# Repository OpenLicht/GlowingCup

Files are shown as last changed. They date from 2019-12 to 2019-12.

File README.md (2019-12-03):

# Glowing Cup

## Summary
The board measures the temperature and adjusts the color accordingly.
The Temperature is determined by three sensors, which provides the mean value
to the microcontroller. It processes and visualizes the data as a color via the built-in RGB LEDs. The board is charged wirelessly using Qi(pronounced CHEE) technology.

## Pictures
| | |
| --- | --- |
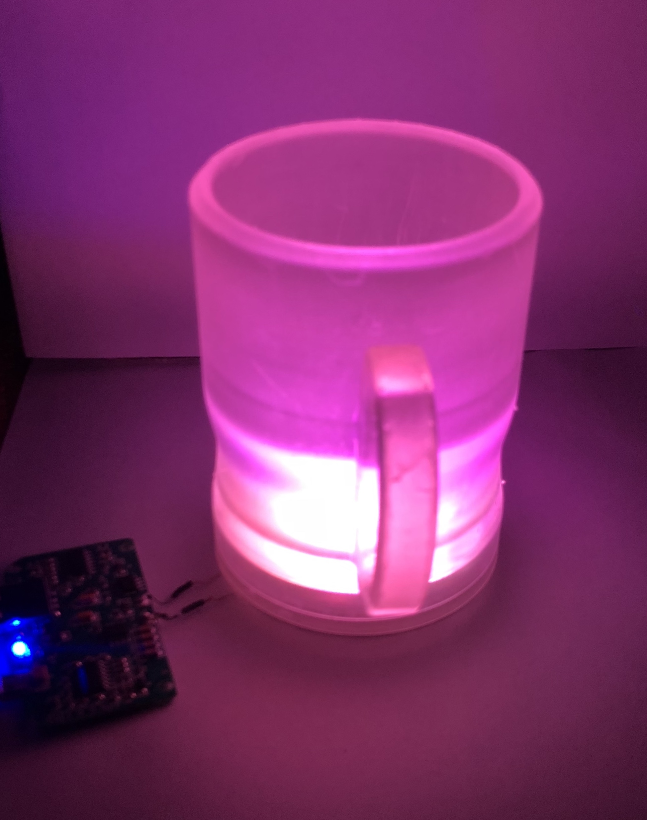
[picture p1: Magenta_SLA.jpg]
Bild1
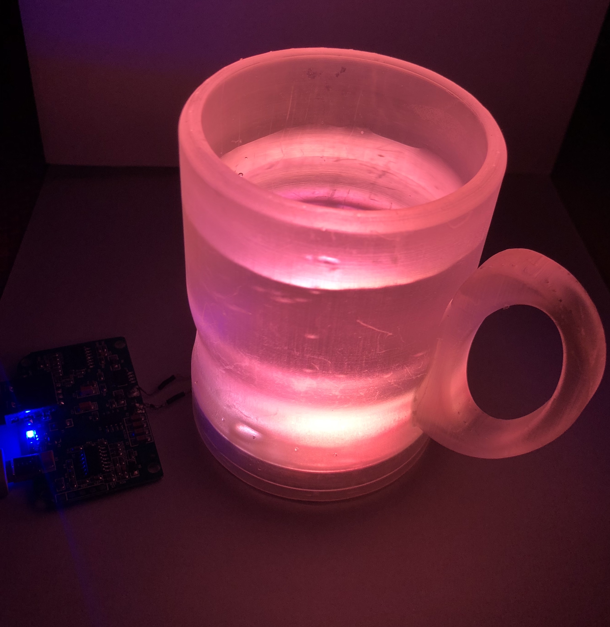
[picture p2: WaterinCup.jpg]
Bild2
|  |  |
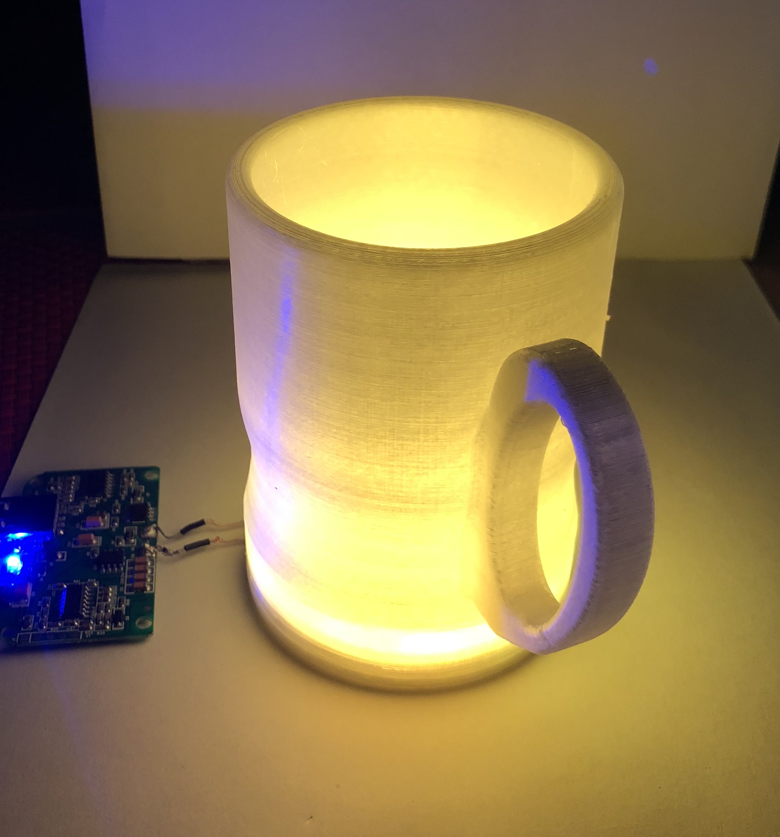
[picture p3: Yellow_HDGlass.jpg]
Bild3
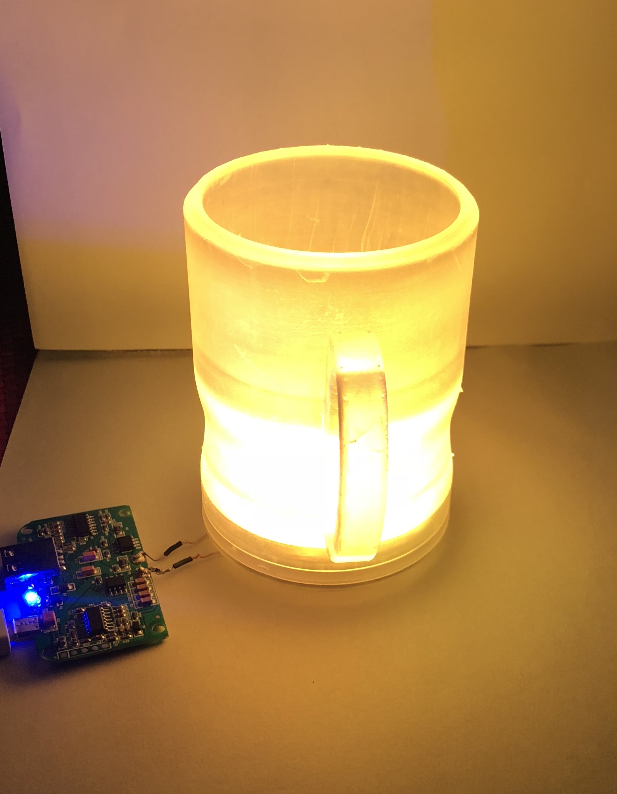
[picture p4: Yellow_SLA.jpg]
Bild4
|  |  |

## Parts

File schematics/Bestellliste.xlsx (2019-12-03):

Bauteile | Im Labor verfügbar? | Anzahl | Preis pro Stück | Kosten | Quelle |  | Nein
WR08X4701FTL - Chipwiderstand, Oberflächenmontage, 4.7 kohm, WR08 Series, 150 V, Dickschicht, 0805 [Metrisch 2012] | Nein | 4 | 0.044 | 0.1760 | http://de.farnell.com/walsin/wr08x4701ftl/dickschichtwiderstand-4k7-1-150v/dp/2502731?st=0805%20widerstand |  | Ja
WR08X1001FTL - Chipwiderstand, Oberflächenmontage, 1 kohm, WR08 Series, 150 V, Dickschicht, 0805 [Metrisch 2012] | Nein | 1 | 0.044 | 0.0440 | http://de.farnell.com/walsin/wr08x1001ftl/dickschichtwiderstand-1k-1-150v/dp/2502670?st=0805%20widerstand |  | Ja
WR08X1002FTL - Chipwiderstand, Oberflächenmontage, 10 kohm, WR08 Series, 150 V, Dickschicht, 0805 [Metrisch 2012] | Nein | 2 | 0.046 | 0.0920 | de.farnell.com/walsin/wr08x1002ftl/dickschichtwiderstand-10k-1-150v/dp/2502671?st=0805%20widerstand
WR08X120 JTL - Chipwiderstand, Oberflächenmontage, 12 ohm, WR08 Series, 150 V, Dickschicht, 0805 [Metrisch 2012] | Nein | 9 | 0.04 | 0.3600 | http://de.farnell.com/walsin/wr08x120-jtl/dicksch-widerstand-12r-5-0-125w/dp/2670937?st=0805%20widerstand
WR08X000 PTL - Chipwiderstand, Oberflächenmontage, 0 ohm, WR08 Series, 150 V, Dickschicht, 0805 [Metrisch 2012], 125 mW | Nein | 1 | 0.043 | 0.0430 | de.farnell.com/walsin/wr08x000-ptl/dickschichtwiderstand-0r-150v/dp/2502664?st=0805%20widerstand
WR08X511 JTL - Chipwiderstand, Oberflächenmontage, 510 ohm, WR08 Series, 150 V, Dickschicht, 0805 [Metrisch 2012] | Nein | 1 | 0.04 | 0.0400 | http://de.farnell.com/walsin/wr08x511-jtl/dicksch-widerstand-510r-5-0-125w/dp/2671053?st=0805%20widerstand
MCTC0525B8871T5E - Chipwiderstand, Oberflächenmontage, Dünnschicht, 8.87 kohm, Baureihe MCT05, 100 V, Dünnschicht 0.1% | Nein | 1 | 0.233 | 0.2330 | http://de.farnell.com/multicomp/mctc0525b8871t5e/d-nnschichtwiderst-8k87-0-1-0/dp/1575895 |  |  | R22
MCWF08U1002BTL - Chipwiderstand, Oberflächenmontage, 10 kohm, MCWF08U Series, 100 V, Dünnschicht 0.1% | Nein | 1 | 0.235 | 0.2350 | http://de.farnell.com/multicomp/mcwf08u1002btl/d-nnsch-widerstand-10k-0-1-0-1w/dp/2694160 |  |  | R21
MCMR04W1R00FTL - Chipwiderstand, Oberflächenmontage, Keramik, 1 ohm, Baureihe MCMR, 50 V, Dickschicht | Nein | 1 | 0.014 | 0.0140 | http://de.farnell.com/multicomp/mcmr04w1r00ftl/keramikwiderstand-1r-1-0-0625w/dp/2072500
MC0805N9R0D500CT - Keramikvielschichtkondensator, SMD, 0805 [Metrisch 2012], 9 pF, 50 V, ± 0.5pF, C0G / NP0 | Nein | 2 | 0.077 | 0.1540 | http://de.farnell.com/multicomp/mc0805n9r0d500ct/kondensator-mlcc-c0g-np0-9pf-50v/dp/1759189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
0805B104K101CT - Keramikvielschichtkondensator, SMD, 0805 [Metrisch 2012], 0.1 µF, 100 V, ± 10%, X7R | Nein | 8 | 0.0485 | 0.3880 | http://de.farnell.com/walsin/0805b104k101ct/kondensator-mlcc-x7r-0-1uf-100v/dp/2496941?st=0,1µF%200805
MC0805N3R0C500CT - Keramikvielschichtkondensator, SMD, 0805 [Metrisch 2012], 3 pF, 50 V, ± 0.25pF, C0G / NP0 | Nein | 2 | 0.0564 | 0.1128 | http://de.farnell.com/multicomp/mc0805n3r0c500ct/kondensator-mlcc-c0g-np0-3pf-50v/dp/1759182?st=3pF%20smd
UZR1H2R2MCL1GB | Nein | 1 | 0.353 | 0.3530 | https://www.mouser.de/ProductDetail/Nichicon/UZR1H2R2MCL1GB?qs=sGAEpiMZZMtZ1n0r9vR22ZeEmyXxpYomhv1G6ZxiR10%3d
GRM219F51E105ZA01D - Keramikvielschichtkondensator, SMD, 0805 [Metrisch 2012], 1 µF, 25 V, +80%, -20%, Y5V, Baureihe GRM | Nein | 2 | 0.0347 | 0.0694 | http://de.farnell.com/murata/grm219f51e105za01d/kondensator-mlcc-y5v-1uf-25v-0805/dp/1828853
LZ2012M100WT - Hochfrequenzinduktivität, Oberflächenm., Baureihe MLZ, 10 µH, 350 mA, 0805 [Metrisch 2012] | Nein | 1 | 0.108 | 0.1080 | http://de.farnell.com/tdk/mlz2012m100wt/induktivit-t-gesch-10uh-20/dp/2215650
B82498B3150J - Hochfrequenzinduktivität, Oberflächenm., Baureihe B82498B, 15 nH, 670 mA, 0805 [Metrisch 2012] | Nein | 1 | 0.302 | 0.3020 | http://de.farnell.com/epcos/b82498b3150j/induktivit-t-bauform-0805-15nh/dp/4000390
SML-D12P8WT86C - LED, 0603, Grün, Oberflächenmontage, 20 mA, 2.2 V, 560 nm | Nein | 1 | 0.169 | 0.1690 | http://de.farnell.com/rohm/sml-d12p8wt86c/led-aec-q101-gr-n-6-3mcd-smd-0603/dp/2687486?st=0603%20led
SML-D12D8WT86C - LED, 0603, Orange, Oberflächenmontage, 20 mA, 2.2 V, 605 nm | Nein | 1 | 0.167 | 0.1670 | http://de.farnell.com/rohm/sml-d12d8wt86c/led-aec-q101-orange-100mcd-smd/dp/2687484?st=0603%20led
CLX6D-FKB-CMPQSGKBB7A363 | Nein | 9 | 0.394 | 3.5460 | https://www.mouser.de/ProductDetail/Cree-Inc/CLX6D-FKB-CMPQSGKBB7A363
LM75ADP,118 - Temperatursensor-IC, Digital, ± 3°C, -55 °C, +125 °C, TSSOP, 8 Pin(s | Nein | 3 | 0.48 | 1.4400 | http://de.farnell.com/nxp/lm75adp-118/ic-temp-sensor-0-125grad-3grad/dp/2301491?st=lm75
ABM8W-20.0000MHZ-4-B1U-T3 | Nein | 1 | 0.525 | 0.5250 | https://www.mouser.de/ProductDetail/ABRACON/ABM8W-200000MHZ-4-B1U-T3/
ABS07-32.768KHZ-7-T - Quarz, 32.768 kHz, SMD, 3.2mm x 1.5mm, 7 pF, 20 ppm, Baureihe ABS07 | Nein | 1 | 0.808 | 0.8080 | http://de.farnell.com/abracon/abs07-32-768khz-7-t/quarz-32-768khz-7pf-smd/dp/1838935?st=ABS07-32.768KHZ-7-T
Doppelschicht-Kondensator 0.47 F 5.5 V (Ø x H) 11.5 mm x 5.5 mm Korchip DCS5R5474HF 1 St. | Nein | 2 | 2.15 | 4.3000 | https://www.conrad.de/de/doppelschicht-kondensator-047-f-55-v-o-x-h-115-mm-x-55-mm-korchip-dcs5r5474hf-1-st-1577023.html
LF33CDT-TR - LDO-Festspannungsregler, 3V bis 16V, 400mV Dropout, 3.3Vout, 0.5Aout, TO-252-3 | Nein | 1 | 0.428 | 0.4280 | http://de.farnell.com/stmicroelectronics/lf33cdt-tr/ldo-reg-16vin-3-3v-0-5a-d-pak/dp/2112623?st=LF33CDT-TR
XMC1402T038X0200AAXUMA1 | Nein | 1 | 3.44 | 3.4400 | https://www.mouser.de/ProductDetail/Infineon/XMC1402T038X0200AAXUMA1/
RedBearLab BLE Nano v2 | Nein | 1 | 20.96 | 20.9600 | https://www.exp-tech.de/plattformen/sonstige/8050/redbearlab-ble-nano-v2
Universal Qi Wireless Receiver Module | Nein | 1 | 15.95 | 15.9500 | https://www.exp-tech.de/zubehoer/sonstige/7724/universal-qi-wireless-receiver-module?number=EXP-R15-1125
WTM505090-10K2-5V-G1 Transmittermodul | Ja | 1 | 21.34 | Im Labor verfügbar | https://www.mouser.de/ProductDetail/TDK/WTM505090-10K2-5V-G1
TMP36GT9Z - Temperatursensor-IC, Spannung, ± 3°C, -40 °C, +125 °C, TO-92, 3 Pin(s) | Nein | 1 | 1.18 | 1.1800 | http://de.farnell.com/analog-devices/tmp36gt9z/sensor-temp-to92-3/dp/1438760?st=tmp36
TL431ACDBZT - Spannungsreferenz, hohe Genauigkeit, Shunt, einstellbar, Baureihe TL431, 2.495V bis 36V, SOT-23-3 | Nein | 1 | 0.269 | 0.2690 | http://de.farnell.com/texas-instruments/tl431acdbzt/spannungsref-shunt-2-495v-36v/dp/2323468?st=tl431
Gesamtkosten |  |  |  | 55.91
 |  |  |  |  |  | R1/R3/R4/R25
 |  |  |  |  |  | R2
 |  |  |  |  |  | R7/R8
 |  |  |  |  |  | R9/R10/R11/R12/R13/R14/R15/R16/R17
 |  |  |  |  |  | R22
 |  |  |  |  |  | R21
 |  |  |  |  |  | C1/C2
 |  |  |  |  |  | C3/C4/C5/C8/C12/C14/c15
 |  |  |  |  |  | C6/C7
 |  |  |  |  |  | C9
 |  |  |  |  |  | C10/C13
 |  |  |  |  |  | L1
 |  |  |  |  |  | L2
 |  |  |  |  |  | D1
 |  |  |  |  |  | D2
 |  |  |  |  |  | Quartz_uC
 |  |  |  |  |  | Quartz_BL
 |  |  |  |  |  | SuperCaps

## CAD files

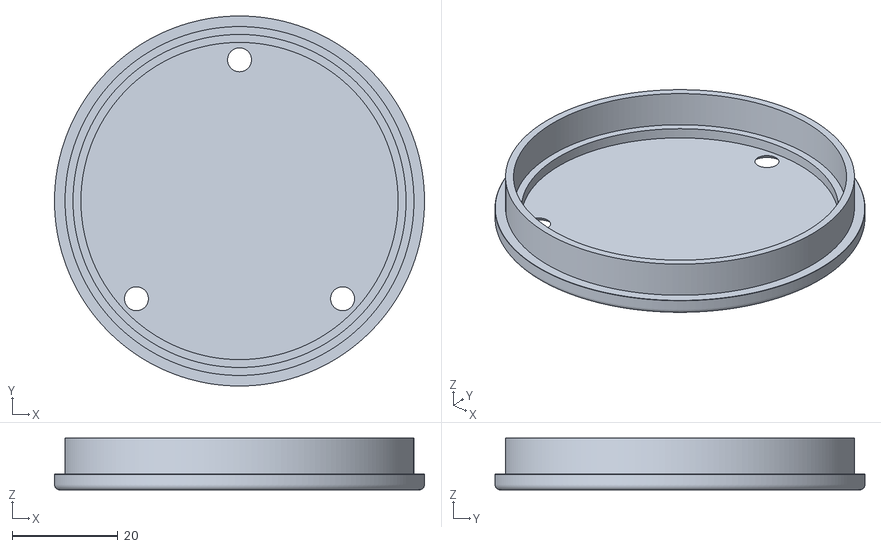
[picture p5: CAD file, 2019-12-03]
3d-files/Tasse_Boden.stl
70.0 x 70.0 x 9.80

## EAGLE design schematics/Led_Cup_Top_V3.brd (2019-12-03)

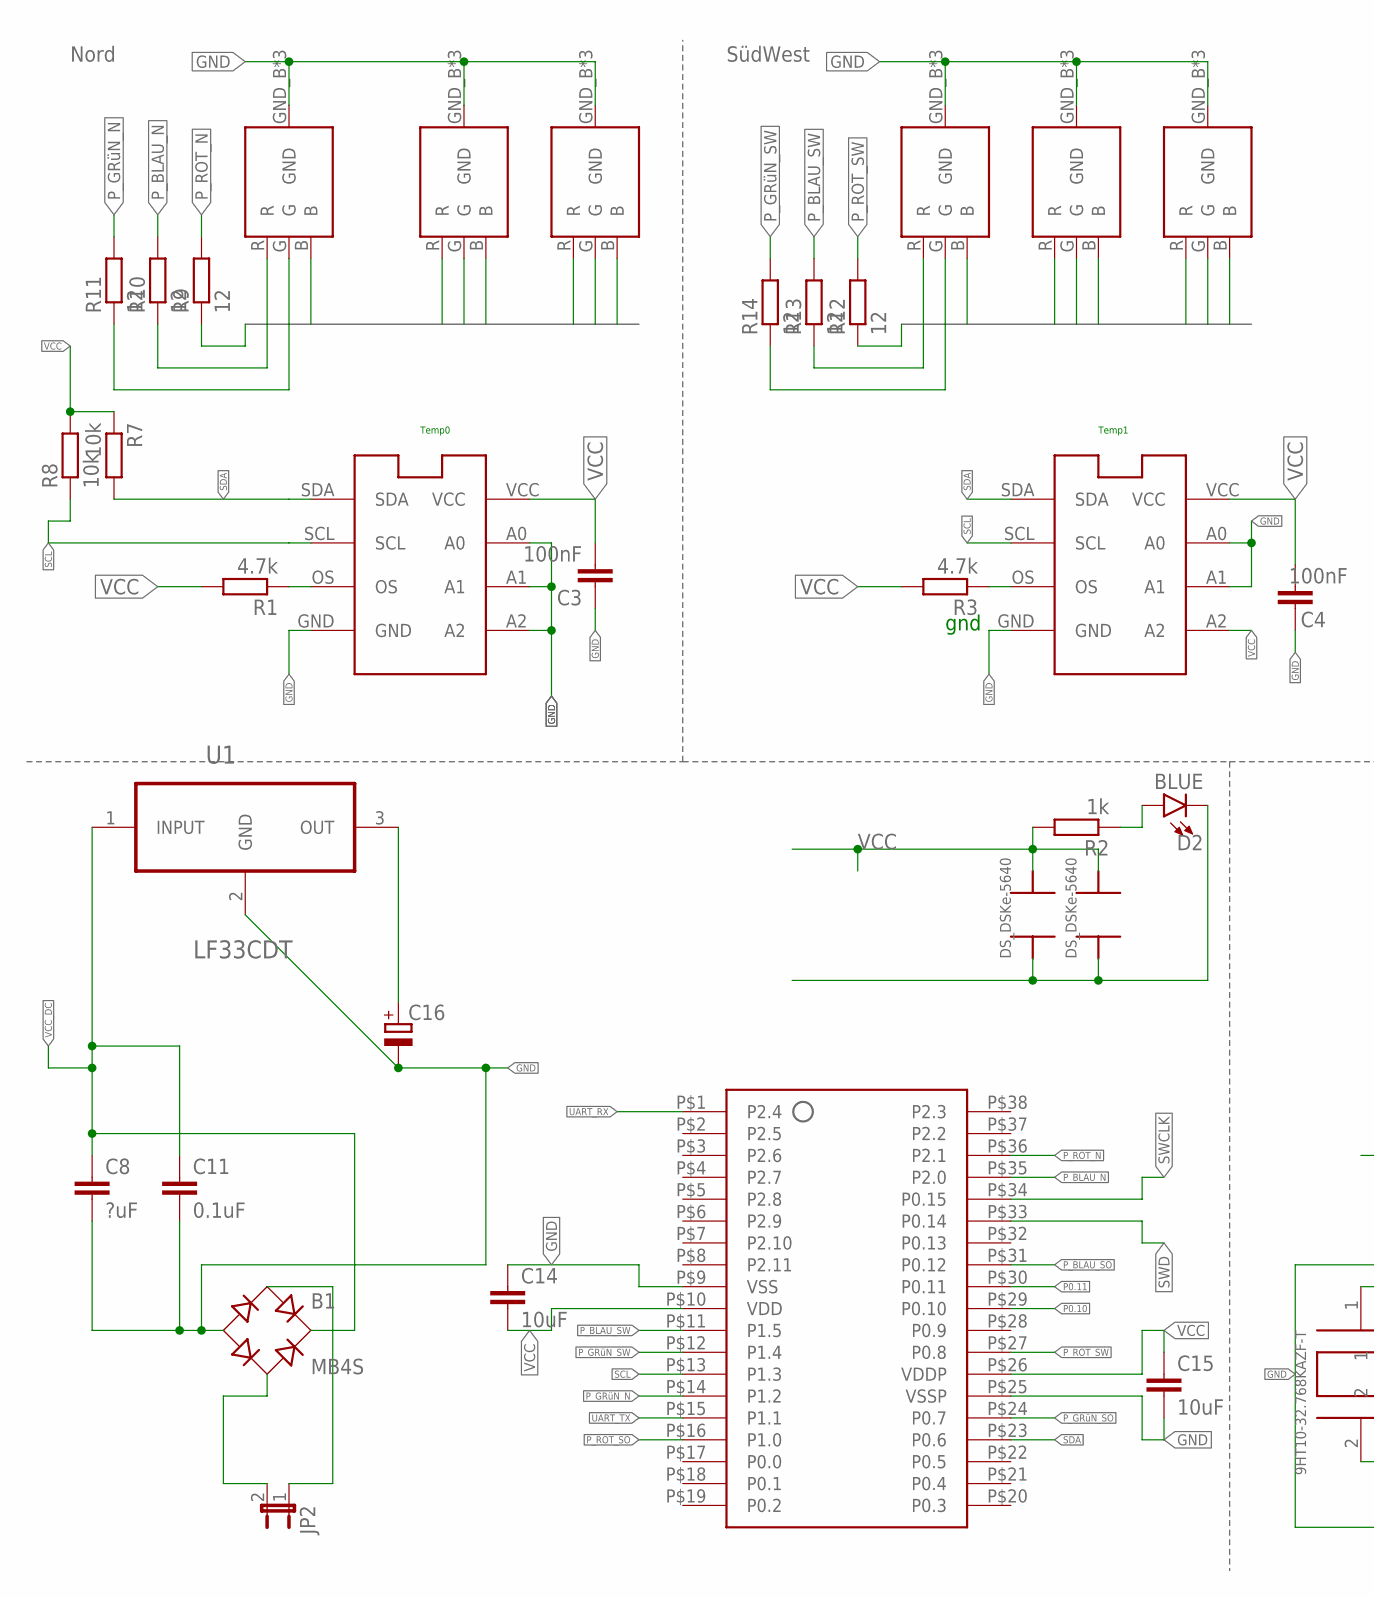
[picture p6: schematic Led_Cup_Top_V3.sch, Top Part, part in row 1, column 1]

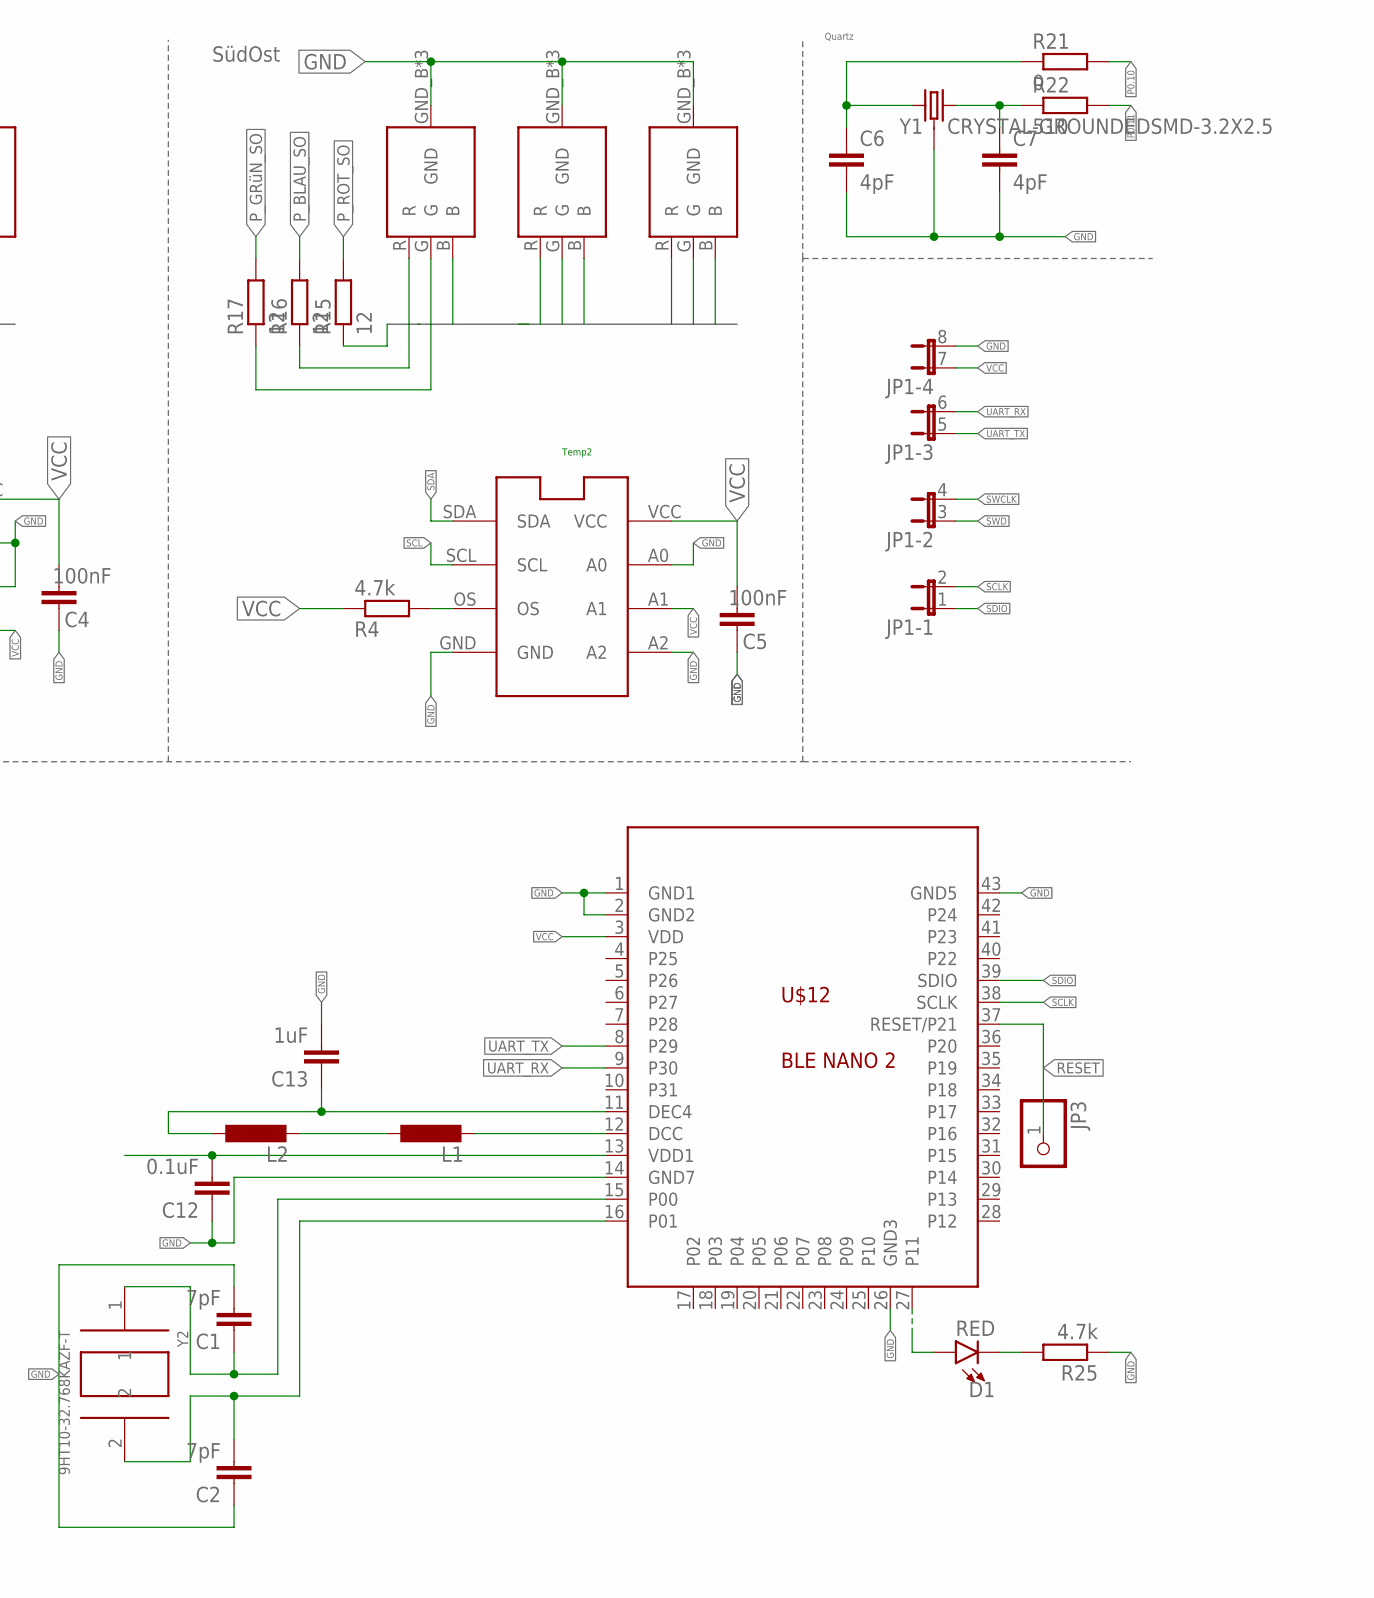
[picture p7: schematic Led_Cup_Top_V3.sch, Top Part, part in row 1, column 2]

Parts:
B1: MB4S; SOIC-4
C1, C2: 7pF; C0805
C3, C4, C5: 100nF; C0805
C6, C7: 4pF; C0805
C8: ?uF; C0805
C11, C12: 0.1uF; C0805
C13: 1uF; C0603
C14, C15: 10uF; C0805
C16: CPOL-EUA/3216-18W; A/3216-18W
D1: RED; LED-0603
D2: BLUE; LED-0603
IC1: LM75Mini_TempS N; LM75MINI
IC2: LM75Mini_TempSW; LM75MINI
IC3: LM75Mini_TempSE; LM75MINI
JP1: JP4QE; JP4Q
JP2: JP1E; JP1
JP3: PINHD-1X1; 1X01
L1, L2: L-EUL2012C; L2012C
R1, R3, R4, R25: 4.7k; R0805
R2: 1k; R0805
R7, R8: 10k; R0805
R9, R10, R11, R12, R13, R14, R15, R16, R17: 12; R0805
R21: 0; R0805
R22: 510; R0805
U1: LF33CDT; TO228P972X240-3N
U$1, U$2, U$3, U$4, U$5, U$6, U$7, U$8, U$9: CREEPLCC6
U$10: XMC1400_38P
U$11, U$13: GOLDCAP
U$12: BLE NANO 2; RBT07
Y1: CRYSTAL-GROUNDEDSMD-3.2X2.5; CRYSTAL-SMD-3.2X2.5MM
Y2: 9HT10-32.768KAZF-T; XTAL320X150X75

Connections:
BLAU_N: R10.1, U$1.B, U$2.B, U$3.B
BLAU_SO: R16.1, U$7.B, U$8.B, U$9.B
BLAU_SW: R13.1, U$4.B, U$5.B, U$6.B
GND: B1.-, C1.2, C2.1, C3.1, C4.1, C5.1, C6.2, C7.2, C8.2, C11.2, C12.1, C13.2, C14.1, C15.2, C16.-, D2.C, IC1.A0, IC1.A1, IC1.A2, IC1.GND, IC2.A0, IC2.A1, IC2.GND, IC3.A0, IC3.A2, IC3.GND, JP1.8 (2), R25.1, U1.2 (GND), U$1.GND_B (GND), U$1.GND_G (GND), U$1.GND_R (GND), U$2.GND_B (GND), U$2.GND_G (GND), U$2.GND_R (GND), U$3.GND_B (GND), U$3.GND_G (GND), U$3.GND_R (GND), U$4.GND_B (GND), U$4.GND_G (GND), U$4.GND_R (GND), U$5.GND_B (GND), U$5.GND_G (GND), U$5.GND_R (GND), U$6.GND_B (GND), U$6.GND_G (GND), U$6.GND_R (GND), U$7.GND_B (GND), U$7.GND_G (GND), U$7.GND_R (GND), U$8.GND_B (GND), U$8.GND_G (GND), U$8.GND_R (GND), U$9.GND_B (GND), U$9.GND_G (GND), U$9.GND_R (GND), U$10.P$9 (VSS), U$10.P$25 (VSSP), U$11.P$1, U$12.1 (GND1), U$12.2 (GND2), U$12.14 (GND7), U$12.26 (GND3), U$12.43 (GND5), U$13.P$1, Y1.2 (3), Y1.4 (3); also elsewhere on the board
GRüN_N: R11.1, U$1.G, U$2.G, U$3.G
GRüN_SO: R17.1, U$7.G, U$8.G, U$9.G
GRüN_SW: R14.1, U$4.G, U$5.G, U$6.G
unnamed: IC1.OS, R1.1
unnamed: IC3.OS, R4.2
unnamed: IC2.OS, R3.1
unnamed 12: C16.+, U1.3 (OUT); also elsewhere on the board
unnamed: B1.~2 (AC2), JP2.2
unnamed: C7.1, R22.1, Y1.3 (2)
unnamed: C6.1, R21.1, Y1.1
unnamed: D2.A, R2.1
unnamed: B1.~1 (AC1), JP2.1
unnamed: L1.2, U$12.12 (DCC)
unnamed: L1.1, L2.2
unnamed: C13.1, L2.1, U$12.11 (DEC4)
unnamed: C1.1, U$12.15 (P00), Y2.1
unnamed: C2.2, U$12.16 (P01), Y2.2
unnamed: D1.C, R25.2
unnamed: D1.A, U$12.27 (P11)
P0.10: R21.2, U$10.P$29 (P0.10)
P0.11: R22.2, U$10.P$30 (P0.11)
P_BLAU_N: R10.2, U$10.P$35 (P2.0)
P_BLAU_SO: R16.2, U$10.P$31 (P0.12)
P_BLAU_SW: R13.2, U$10.P$11 (P1.5)
P_GRüN_N: R11.2, U$10.P$14 (P1.2)
P_GRüN_SO: R17.2, U$10.P$24 (P0.7)
P_GRüN_SW: R14.2, U$10.P$12 (P1.4)
P_ROT_N: R9.2, U$10.P$36 (P2.1)
P_ROT_SO: R15.2, U$10.P$16 (P1.0)
P_ROT_SW: R12.2, U$10.P$27 (P0.8)
RESET: JP3.1, U$12.37 (RESET/P21)
ROT_N: R9.1, U$1.R, U$2.R, U$3.R
ROT_SO: R15.1, U$7.R, U$8.R, U$9.R
ROT_SW: R12.1, U$4.R, U$5.R, U$6.R
SCL: IC1.SCL, IC2.SCL, IC3.SCL, R8.1, U$10.P$13 (P1.3)
SCLK: JP1.2, U$12.38 (SCLK)
SDA: IC1.SDA, IC2.SDA, IC3.SDA, R7.2, U$10.P$23 (P0.6)
SDIO: JP1.1, U$12.39 (SDIO)
SWCLK: JP1.4 (2), U$10.P$34 (P0.15)
SWD: JP1.3 (1), U$10.P$33 (P0.14)
UART_RX: JP1.6 (2), U$10.P$1 (P2.4), U$12.9 (P30)
UART_TX: JP1.5 (1), U$10.P$15 (P1.1), U$12.8 (P29)
VCC: C3.2, C4.2, C5.2, C12.2, C14.2, C15.1, IC1.VCC, IC2.A2, IC2.VCC, IC3.A1, IC3.VCC, JP1.7 (1), R1.2, R2.2, R3.2, R4.1, R7.1, R8.2, U$10.P$10 (VDD), U$10.P$26 (VDDP), U$11.P$2, U$12.3 (VDD), U$12.13 (VDD1), U$13.P$2; also elsewhere on the board
VCC_DC: B1.+, C8.1, C11.1, U1.1 (INPUT)

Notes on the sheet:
gnd
Nord
SüdWest
SüdOst
Quartz
Temp0
Temp1
Temp2

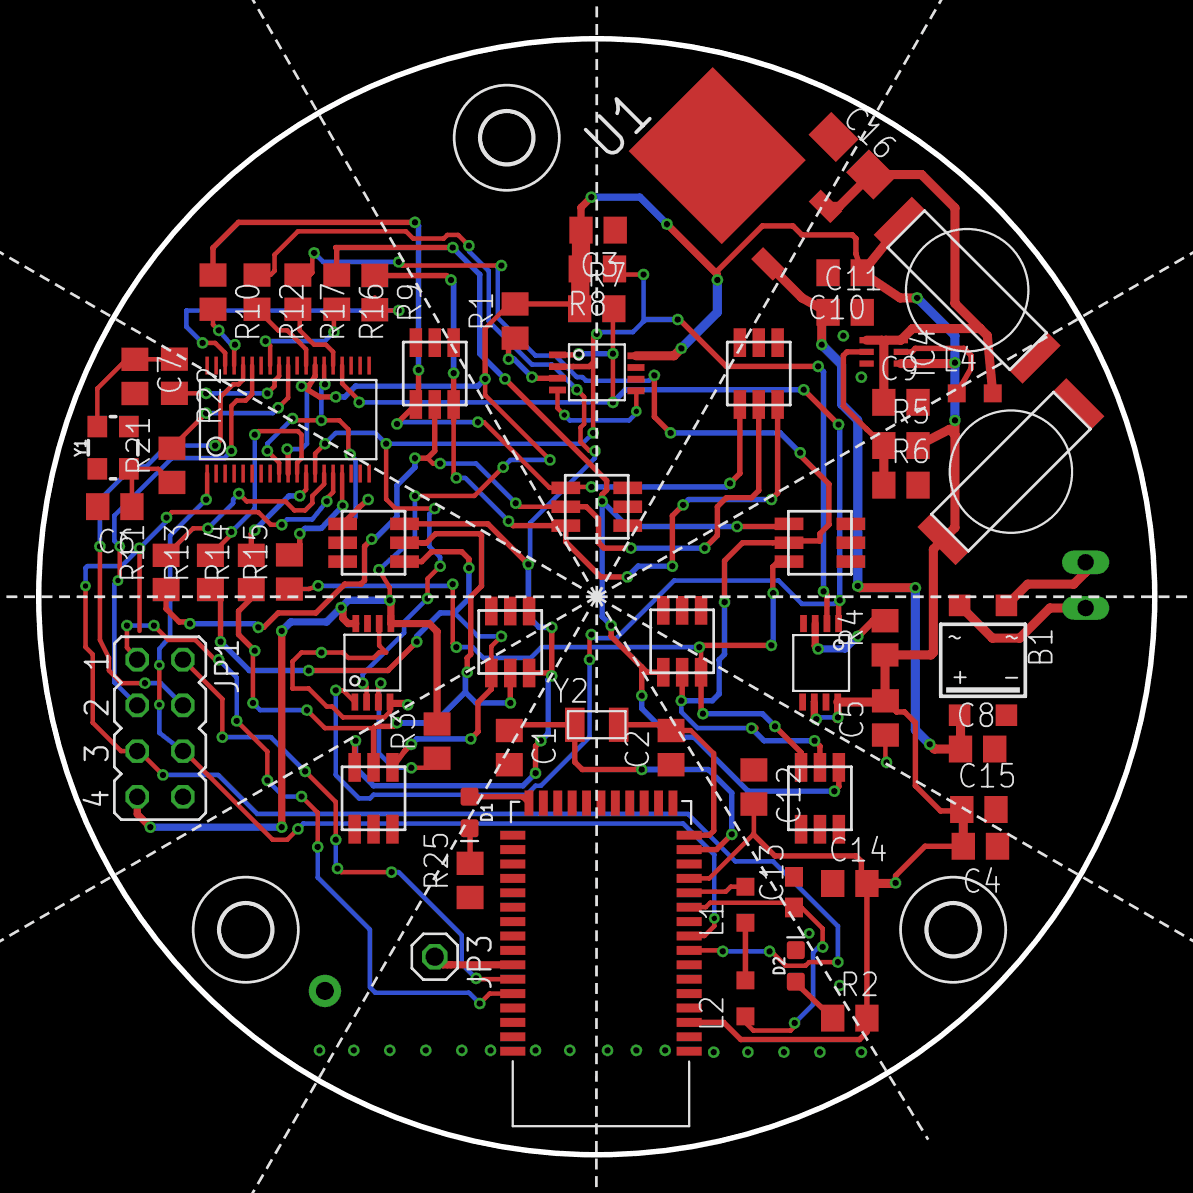
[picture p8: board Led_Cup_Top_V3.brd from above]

Board: 2 copper layers, 62.0 x 62.0 mm, 68 parts (1 on the bottom side), 50 nets.

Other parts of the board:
C9, C10: ?uF; C0805
IC4: TPS61220DCKT; SOIC65P210X95-6N
L4: L2012C
R5: 1M; R0805
R6: 178k; R0805
U$15, U$16, U$17: 2,8

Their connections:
GND: C9.2, C10.2, IC4.3, R6.2; also elsewhere on the board
unnamed 12: C9.1, IC4.1, IC4.6, L4.2; also elsewhere on the board
unnamed: IC4.5, L4.1
unnamed: IC4.2, R5.1, R6.1
VCC: C10.1, IC4.4, R5.2; also elsewhere on the board

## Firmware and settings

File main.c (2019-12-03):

/*
 * main.c
 *
 *  Created on: 2017 Oct 25 16:08:21
 *  Author: Tobias
 */

#include "lm75.h"              //Declarations from DAVE Code Generation (includes SFR declaration)

unsigned int lm75_N();
unsigned int lm75_SW();
unsigned int lm75_SE();

int delay(int);
void setupLED();
int handleTemp();
void colorALL(uint16_t, uint16_t, uint16_t);
void color_N(uint16_t blue, uint16_t red, uint16_t green);
void color_SW(uint16_t blue, uint16_t red, uint16_t green);
void color_SE(uint16_t blue, uint16_t red, uint16_t green);

uint8_t trigger[1];

uint8_t usb = 0;

static uint8_t index_N, index_SW, index_SE;
static uint8_t data_N;
static uint8_t data_SW;
static uint8_t data_SE;
int8_t temp_N[1];
int8_t temp_SW[1];
uint8_t temp_SE[1];
uint8_t average_temp[1];
uint8_t rgb[4] = { 0 };
int a;

/**

 * @brief main() - Application entry point
 *
 * <b>Details of function</b><br>
 * This routine is the application entry point. It is invoked by the device startup code. It is responsible for
 * invoking the APP initialization dispatcher routine - DAVE_Init() and hosting the place-holder for user application
 * code.
 */

int main(void) {
	DAVE_STATUS_t status;
//	uint32_t index = 0;

	status = DAVE_Init(); /* Initialization of DAVE APPs  */

	if (status != DAVE_STATUS_SUCCESS) {
		/* Placeholder for error handler code. The while loop below can be replaced with an user error handler. */
		XMC_DEBUG("DAVE APPs initialization failed\n");

		while (1U) {

		}
	}
	setupLED();

//	PWM_SetDutyCycle(&PWM_0, 255);		// Red
	uint8_t rgb[4] = { 0 };
	/* Placeholder for user application code. The while loop below can be replaced with user application code. */
	while (1U) {

//      Only Transmit UART
//		UART_Transmit(&UART, "Hallo", sizeof("Hallo"));
		//lm75_SW();
		//lm75_SE();
		//	lm75_N();
//
//			handleTemp();

		delay(1000);

		if (UART_Receive(&UART_BL, rgb, 4) == UART_STATUS_SUCCESS) {
			if (rgb[0] == 1) {

				a = 1;
				while (a == 1) {
					lm75_N();
					lm75_SW();

					lm75_SE();
					handleTemp();
					if (rgb[0] != 1) {
						a = 0;
					}
				}
			}

			if (rgb[0] == 2) {
				while (rgb[0] == 2) {
					UART_Receive(&UART_BL, rgb, 4);
					color_N(rgb[1], rgb[2], rgb[3]);
				}
			}

			if (rgb[0] == 3) {
				while (rgb[0] == 3) {
					UART_Receive(&UART_BL, rgb, 4);
					color_SW(rgb[1], rgb[2], rgb[3]);
				}
			}

			if (rgb[0] == 4) {
				while (rgb[0] == 4) {
					UART_Receive(&UART_BL, rgb, 4);
					color_SE(rgb[1], rgb[2], rgb[3]);
				}
			}

			if (rgb[0] == 66) {
				setupLED();
				rgb[0] = 0;
			}
		} else if (rgb[0] != 1 && rgb[0] != 2 && rgb[0] != 3 && rgb[0] != 4
				&& rgb[0] != 66) {
			lm75_N();
			lm75_SW();
			lm75_SE();
			handleTemp();
		}

	}
	return 1U;

}

// UART output to console

unsigned int lm75_N() {

	index_N = 0;

	I2C_MASTER_SendStart(&I2C_MASTER_0, TEMP_ADDRESS_W_N, XMC_I2C_CH_CMD_WRITE); //
	while (I2C_MASTER_GetFlagStatus(&I2C_MASTER_0,
			XMC_I2C_CH_STATUS_FLAG_ACK_RECEIVED) == 0U) {

	}
	I2C_MASTER_ClearFlag(&I2C_MASTER_0, XMC_I2C_CH_STATUS_FLAG_ACK_RECEIVED);
// write to address 0
	I2C_MASTER_TransmitByte(&I2C_MASTER_0, TEMP_ADDRESS_T); //0x00
	while (I2C_MASTER_GetFlagStatus(&I2C_MASTER_0,
			XMC_I2C_CH_STATUS_FLAG_ACK_RECEIVED) == 0U) {
		// wait for ACK
	}

	I2C_MASTER_ClearFlag(&I2C_MASTER_0, XMC_I2C_CH_STATUS_FLAG_ACK_RECEIVED);
	I2C_MASTER_SendRepeatedStart(&I2C_MASTER_0, TEMP_ADDRESS_W_N,
			XMC_I2C_CH_CMD_READ);
	while (I2C_MASTER_GetFlagStatus(&I2C_MASTER_0,
			XMC_I2C_CH_STATUS_FLAG_ACK_RECEIVED) == 0U) {
		// wait for ACK
	}
	I2C_MASTER_ClearFlag(&I2C_MASTER_0, XMC_I2C_CH_STATUS_FLAG_ACK_RECEIVED);
	while (index_N < 16) {
		I2C_MASTER_ReceiveACK(&I2C_MASTER_0);
		index_N++;
	}
// only for the last byte
	I2C_MASTER_ReceiveNACK(&I2C_MASTER_0);
//Wait when Rx FIFO is empty
	while (!I2C_MASTER_IsRXFIFOEmpty(&I2C_MASTER_0)) {
		data_N = I2C_MASTER_GetReceivedByte(&I2C_MASTER_0);
	}
	temp_N[0] = data_N;

	I2C_MASTER_SendStop(&I2C_MASTER_0);

	delay(750);

	return (temp_N);

}
unsigned int lm75_SW() {

	index_SW = 0;

	I2C_MASTER_SendStart(&I2C_MASTER_0, TEMP_ADDRESS_W_SW,
			XMC_I2C_CH_CMD_WRITE);
	while (I2C_MASTER_GetFlagStatus(&I2C_MASTER_0,
			XMC_I2C_CH_STATUS_FLAG_ACK_RECEIVED) == 0U) {

	}
	I2C_MASTER_ClearFlag(&I2C_MASTER_0, XMC_I2C_CH_STATUS_FLAG_ACK_RECEIVED);
// write to address 0
	I2C_MASTER_TransmitByte(&I2C_MASTER_0, TEMP_ADDRESS_T); //0x00
	while (I2C_MASTER_GetFlagStatus(&I2C_MASTER_0,
			XMC_I2C_CH_STATUS_FLAG_ACK_RECEIVED) == 0U) {
// wait for ACK
	}

	I2C_MASTER_ClearFlag(&I2C_MASTER_0, XMC_I2C_CH_STATUS_FLAG_ACK_RECEIVED);
	I2C_MASTER_SendRepeatedStart(&I2C_MASTER_0, TEMP_ADDRESS_W_SW,
			XMC_I2C_CH_CMD_READ);
	while (I2C_MASTER_GetFlagStatus(&I2C_MASTER_0,
			XMC_I2C_CH_STATUS_FLAG_ACK_RECEIVED) == 0U) {
// wait for ACK
	}
	I2C_MASTER_ClearFlag(&I2C_MASTER_0, XMC_I2C_CH_STATUS_FLAG_ACK_RECEIVED);
	while (index_SW < 16) {
		I2C_MASTER_ReceiveACK(&I2C_MASTER_0);
		index_SW++;
	}
// only for the last byte
	I2C_MASTER_ReceiveNACK(&I2C_MASTER_0);
//Wait when Rx FIFO is empty
	while (!I2C_MASTER_IsRXFIFOEmpty(&I2C_MASTER_0)) {
		data_SW = I2C_MASTER_GetReceivedByte(&I2C_MASTER_0);
	}
	temp_SW[0] = data_SW;

	I2C_MASTER_SendStop(&I2C_MASTER_0);

	delay(750);

	return (temp_SW[0]);

}

unsigned int lm75_SE() {

	index_SE = 0;

	I2C_MASTER_SendStart(&I2C_MASTER_0, TEMP_ADDRESS_W_SE,
			XMC_I2C_CH_CMD_WRITE);
	while (I2C_MASTER_GetFlagStatus(&I2C_MASTER_0,
			XMC_I2C_CH_STATUS_FLAG_ACK_RECEIVED) == 0U) {

	}
	I2C_MASTER_ClearFlag(&I2C_MASTER_0, XMC_I2C_CH_STATUS_FLAG_ACK_RECEIVED);
// write to address 0
	I2C_MASTER_TransmitByte(&I2C_MASTER_0, TEMP_ADDRESS_T); //0x00
	while (I2C_MASTER_GetFlagStatus(&I2C_MASTER_0,
			XMC_I2C_CH_STATUS_FLAG_ACK_RECEIVED) == 0U) {
// wait for ACK
	}

	I2C_MASTER_ClearFlag(&I2C_MASTER_0, XMC_I2C_CH_STATUS_FLAG_ACK_RECEIVED);
	I2C_MASTER_SendRepeatedStart(&I2C_MASTER_0, TEMP_ADDRESS_W_SE,
			XMC_I2C_CH_CMD_READ);
	while (I2C_MASTER_GetFlagStatus(&I2C_MASTER_0,
			XMC_I2C_CH_STATUS_FLAG_ACK_RECEIVED) == 0U) {
// wait for ACK
	}
	I2C_MASTER_ClearFlag(&I2C_MASTER_0, XMC_I2C_CH_STATUS_FLAG_ACK_RECEIVED);
	while (index_SE < 16) {
		I2C_MASTER_ReceiveACK(&I2C_MASTER_0);
		index_SE++;
	}
// only for the last byte
	I2C_MASTER_ReceiveNACK(&I2C_MASTER_0);
//Wait when Rx FIFO is empty
	while (!I2C_MASTER_IsRXFIFOEmpty(&I2C_MASTER_0)) {
		data_SE = I2C_MASTER_GetReceivedByte(&I2C_MASTER_0);
	}
	temp_SE[0] = data_SE;

	I2C_MASTER_SendStop(&I2C_MASTER_0);

	delay(750);

	return (temp_SE[0]);

}

int delay(int x) {
	for (int i = 0; i < x; i++)
		;
}

void setupLED() {

	PWM_SetDutyCycle(&Red_N, 0);
	PWM_SetDutyCycle(&Green_N, 0);
	PWM_SetDutyCycle(&Blue_N, 0);
	PWM_SetDutyCycle(&Red_SW, 0);
	PWM_SetDutyCycle(&Green_SW, 0);
	PWM_SetDutyCycle(&Blue_SW, 0);
	PWM_SetDutyCycle(&Red_SE, 0);
	PWM_SetDutyCycle(&Green_SE, 0);
	PWM_SetDutyCycle(&Blue_SE, 0);

}

int handleTemp() {

	average_temp[0] = ((data_N + data_SW + data_SE) / 3);
	UART_Transmit(&UART_BL, average_temp, 1);

	if (average_temp[0] < 0) {
		colorALL(0xE8, 0xFF, 0xFA);
	}
	if (average_temp[0] >= 0 && average_temp[0] <= 5) {
		colorALL(0xA3, 0xE4, 0xFF);
	}
	if (average_temp[0] > 5 && average_temp[0] <= 10) {
		colorALL(0x84, 0xDA, 0xFF);
	}
	if (average_temp[0] > 10 && average_temp[0] <= 15) {
		colorALL(0x96, 0xB7, 0xFF);
	}
	if (average_temp[0] > 15 && average_temp[0] <= 20) {
		colorALL(0x00, 0x00, 0xFF);
	}
	if (average_temp[0] > 20 && average_temp[0] <= 25) {
		colorALL(0xFF, 0x80, 0x00);
	}
	if (average_temp[0] > 25 && average_temp[0] <= 30) {
		colorALL(0xFF, 0x5F, 0x2E);
		//colorALL(0xFF,0xFF,0xFF);
		//colorALL(0x00, 0xFF, 0x00);
	}
	if (average_temp[0] > 30 && average_temp[0] <= 35) {
		colorALL(0xFF, 0x68, 0x2E);
//colorALL(0xFF, 0x00,0x00);
	}
	if (average_temp[0] > 35 && average_temp[0] <= 40) {
		colorALL(0xFF, 0x5F, 0x19);
	}
	if (average_temp[0] > 40 && average_temp[0] <= 45) {
		colorALL(0xFF, 0x5F, 0x00);
	}
	if (average_temp[0] > 45 && average_temp[0] <= 50) {
		colorALL(0xFF, 0x4C, 0x00);
	}
	if (average_temp[0] > 50 && average_temp[0] <= 60) {
		colorALL(0xFF, 0x40, 0x2E);
	}
	if (average_temp[0] > 60 && average_temp[0] <= 75) {
		colorALL(0xFF, 0x40, 0x19);
	}
	if (average_temp[0] > 75 && average_temp[0] <= 100) {
		colorALL(0xFF, 0x33, 0x16);
	}
	if (average_temp[0] > 100) {
		colorALL(0xFF, 0x00, 0x00);
	}
//	if (data2 >= 24 || data <= 30){
//		color(0xFF,0x00,0x00);
//	}
//	if (data2 >= 27)
//		color(0x00,0xFF,0x00);
//	if(data2 >= 30)
//		color(0x00,0x00,0xFF);
}

void colorALL(uint16_t red, uint16_t green, uint16_t blue) {
	uint16_t redPortion = red * 10000 / 255;
	uint16_t greenPortion = green * 10000 / 255;
	uint16_t bluePortion = blue * 10000 / 255;

	PWM_SetDutyCycle(&Red_N, redPortion);
	PWM_SetDutyCycle(&Green_N, greenPortion);
	PWM_SetDutyCycle(&Blue_N, bluePortion);
	PWM_SetDutyCycle(&Red_SW, redPortion);
	PWM_SetDutyCycle(&Green_SW, greenPortion);
	PWM_SetDutyCycle(&Blue_SW, bluePortion);
	PWM_SetDutyCycle(&Red_SE, redPortion);
	PWM_SetDutyCycle(&Green_SE, greenPortion);
	PWM_SetDutyCycle(&Blue_SE, bluePortion);
}

void color_N(uint16_t red, uint16_t green, uint16_t blue) {
	uint16_t redPortion = red * 10000 / 255;
	uint16_t greenPortion = green * 10000 / 255;
	uint16_t bluePortion = blue * 10000 / 255;

	PWM_SetDutyCycle(&Red_N, redPortion);
	PWM_SetDutyCycle(&Green_N, greenPortion);
	PWM_SetDutyCycle(&Blue_N, bluePortion);
}

void color_SW(uint16_t red, uint16_t green, uint16_t blue) {

	uint16_t redPortion = red * 10000 / 255;
	uint16_t greenPortion = green * 10000 / 255;
	uint16_t bluePortion = blue * 10000 / 255;

	PWM_SetDutyCycle(&Red_SW, redPortion);
	PWM_SetDutyCycle(&Green_SW, greenPortion);
	PWM_SetDutyCycle(&Blue_SW, bluePortion);
}

void color_SE(uint16_t red, uint16_t green, uint16_t blue) {
	uint16_t redPortion = red * 10000 / 255;
	uint16_t greenPortion = green * 10000 / 255;
	uint16_t bluePortion = blue * 10000 / 255;

	PWM_SetDutyCycle(&Red_SE, redPortion);
	PWM_SetDutyCycle(&Green_SE, greenPortion);
	PWM_SetDutyCycle(&Blue_SE, bluePortion);
}

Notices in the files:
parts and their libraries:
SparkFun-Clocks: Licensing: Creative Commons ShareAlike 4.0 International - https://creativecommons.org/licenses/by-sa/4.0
